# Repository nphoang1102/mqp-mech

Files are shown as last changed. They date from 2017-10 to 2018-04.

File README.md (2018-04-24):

# WPI's MQP Yale's Open Hand Hardware Design
This repository is the hardware design iteration for the Yale's Open Hand MQP at WPI. Please find under the A, B, C term folders the iterations and README.md file that will describe the contain of each folders.

Everything in this repository requires SolidWork 2018 to open and view. The final assembly file can be accessed via C-term/Testing/test_hand_(FINISHED).SLDASM.

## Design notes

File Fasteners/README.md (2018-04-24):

# List of nuts and screws used for WPI MQP Yale's Open Hand

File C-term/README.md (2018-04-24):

# MQP Yale's Open Hand Prototype

### Modified Parts
The files in this folder are modifications to _Iteration 2 model_ to address the problem gear positioning and incorporate PCB board and housing to the current base for a complete hand.
The modifications are:
  - Base: add mounting column onto base for PCB board mount.
  - Gear finger: increase center hole size to fit hollow shaft whichh will fix the position of the gear.
  - Mount motors: change to account for size of the motor.
  - Housing: housing with air ventillation system for cooling motors.
  
### Mounting Parts
The files in this folder are off-shelf parts:
  - DC fan models.
  - Housing for glove electric board.
  - Adapter to Baxter arm model.

### PCB Mount
The files in this folder is the PCB Board model.

### STL toPrint
Dedicated folder for STL files and 3D printing requests.

### Testing
The files in this folder are assemblies for interference check of final prototype.

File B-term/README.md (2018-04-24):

# MQP Yale's Open Hand Iteration 1 & 2

### ReflexOne Finger
The file in this folder is assembly of finger model of Reflex One (source from *_RightHand Robotics_*). 

### Prototype 1
The files in this folder are for iteration 1 model: 
  - Change in close distance between two front fingers.
  - Introduce new gear type - two stage gear, to reduce number of gears thus reduce total base size.

The files are:
  - Motor models: AX12 (with removed back cover) and XL320.
  - Mounting models for motors.
  - Gear models.
  - Base models for hand: top plate and bottom plate.
  - Assembly test models: 
    - Model to verify position of gears and motors.
    - Model of AX12 motor with pulley attached.
    - Model of full assembly to check interference.
  - Excel file of ratio calculations generated from Python script in A-term folder.
    - May use database software to find desired torque reduction ratio with related gear dimensions by importing data from _Ratio Calculation.xlsx_.
  - Archive file of STL files for 3D printing.

The purpose of iteration 1:
  - Test the new design of two front finger gears with controlled glove
  
### Prototype 1 Fixes (Not Prototype 2 Yet)
The files in this folder are fixes for iteration 1 model to make it performs better and smoother.
The files are the same as in _Prototype 1_ folder with adjusted changes in each file.

### Prototype 2
The files in this folder are for iteration 2 model:
  - Change in distance of two front fingers to avoid interference of two finger knuckles.
  - Change in base shape for aesthetic purpose.

The file types are the same as in _Prototype 1_ folder with addition of a separated folder for STL files.
The file types are re-named for searching purpose:
  - *gear_A*: types of gear.
  - *mount_A*: types of mount.
  - *base_A*: types of base.
  - *test_A*: types of testing models.

Everything in this folder requires SolidWork 2018, Microsoft Excel, and Word Editor (or PyCharm for the Python script) to open and view.

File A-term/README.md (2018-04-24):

# MQP Yale's Open Hand Iteration 0

The files under folder _ReflexOne Finger_ is assembly of finger model of Reflex One (source from **_RightHand Robotics_**). This model is also used for subsequent iterations for interference check.

The files in this folder are:
- Motor models: AX12 (with removed back cover) and XL320.
- Mounting models for motors.
- Gear models: to create new gear models with different dimension, make a copy of _Gear.SLDPRT_ and modify to desired dimension.
- Base models for hand: top plate and bottom plate.
- Assembly test models:
  - Model to verify position of gears and motors.
  - Model of AX12 motor with pulley attached.
  - Model of full assembly to check interference.
- Python script:
  - To create list of gear dimensions and related torque reduction ratio then export to _Gear Measurements.xlsx_.
  - May use database software to find desired torque reduction ratio with related gear dimensions by importing data from _Gear Measurements.xlsx_.

The purpose of iteration 0:
- Test the mechanism: gear train.
- Verify how well the 3D printed parts assembled together.
- Verify how well the details of parts were printed.

Everything in this folder requires SolidWork 2018, Microsoft Excel, and Word Editor (or PyCharm for the Python script) to open and view.

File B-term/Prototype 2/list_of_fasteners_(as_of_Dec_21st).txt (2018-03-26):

Screws:
M2 x 35mm
M3 x 6mm
M3 x 22mm
M3 x 35mm
M4 x 18mm
M4 x 20mm
M4 x 25mm
M4 x 40mm
M6 x 20mm

Nuts:
M3
M4
M6

Shaft:
30mm x 2mm round shaft: 20

Nozzle: 0.25/ 0.3/ 0.35/ 0.4/ 0.5/ 0.8

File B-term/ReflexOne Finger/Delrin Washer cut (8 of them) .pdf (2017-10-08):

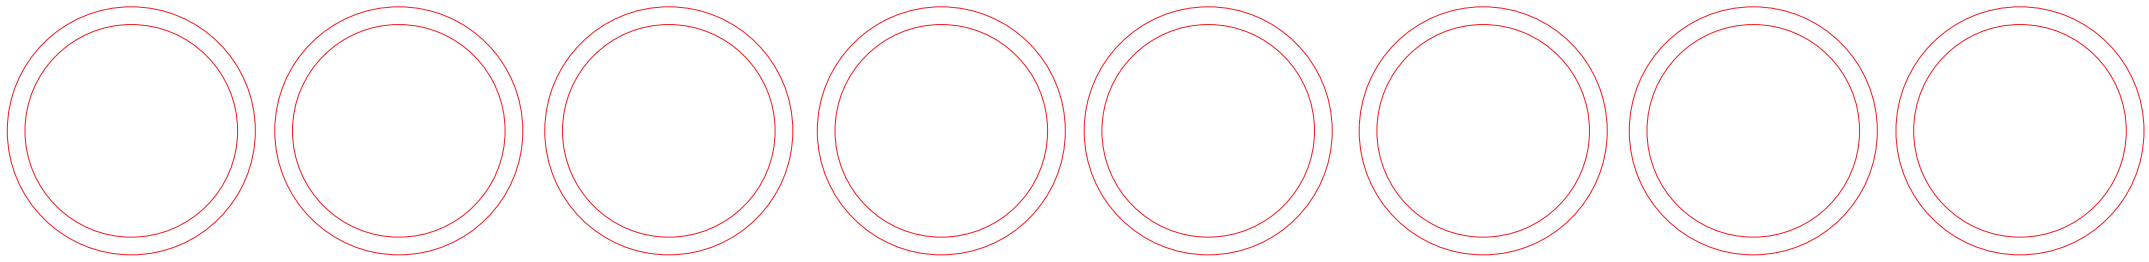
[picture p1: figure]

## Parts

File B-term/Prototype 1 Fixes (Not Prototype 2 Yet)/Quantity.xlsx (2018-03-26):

Parts | Quantity
XL320_thumb_mount | 2
knuckle_mount_test_modified | 1
AX12_thumb_mount | 1
AX12_fingers_mount | 1
two_stage_gear | 1
drive_gear | 1
finger_gear_left | 1
finger_gear_right | 1
base_prototype_test | 1
top_part_base_prototype | 1
TOTAL | 11

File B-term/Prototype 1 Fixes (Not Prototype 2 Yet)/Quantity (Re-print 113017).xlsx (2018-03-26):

Parts | Quantity
AX12_fingers_mount | 1
two_stage_gear | 1
gear_rod | 1
TOTAL | 3

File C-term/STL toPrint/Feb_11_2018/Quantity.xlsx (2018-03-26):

Parts | Quantity
base_prototype_bottom_(Feb_9_2018) | 1
base_prototype_top_(Feb_9_2018) | 1
mount_finger_left | 1
mount_finger_right | 1
mount_thumb | 1
Total | 5

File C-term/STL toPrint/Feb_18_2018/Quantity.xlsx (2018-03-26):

Parts | Quantity
base_prototype_bottom_(Feb_18_2018) | 1
base_prototype_top_(Feb_18_2018) | 1
mount_finger_left | 1
mount_finger_right | 1
glove_housing_top | 1
glove_housing_bottom | 1
Total | 6

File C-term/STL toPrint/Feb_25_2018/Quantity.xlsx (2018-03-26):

Parts | Quantity
housing | 1
mount_finger_left | 1
mount_finger_right | 1
Total | 3

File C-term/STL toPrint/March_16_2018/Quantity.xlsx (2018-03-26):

Parts | Quantity
glove_housing_top | 1
glove_housing_bottom | 1
camera_adapter_base_modified | 1
Total | 3

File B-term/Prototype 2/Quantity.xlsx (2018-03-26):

Parts | Quantity
base_prototype_bottom | 1
base_prototype_top | 1
gear_drive | 1
gear_finger_left | 1
gear_finger_right | 1
gear_intermediate | 1
gear_two_stage | 1
housing | 1
mount_finger_left | 1
mount_finger_right | 1
mount_knuckle_test_modified | 1
mount_thumb | 1
mount_XL320_drive | 1
mount_XL320_thumb | 1
TOTAL | 14

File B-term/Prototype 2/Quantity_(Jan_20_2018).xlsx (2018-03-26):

Parts | Quantity
base_prototype_top_(Jan_20_2018) | 1
shaft_connector | 8
TOTAL | 9

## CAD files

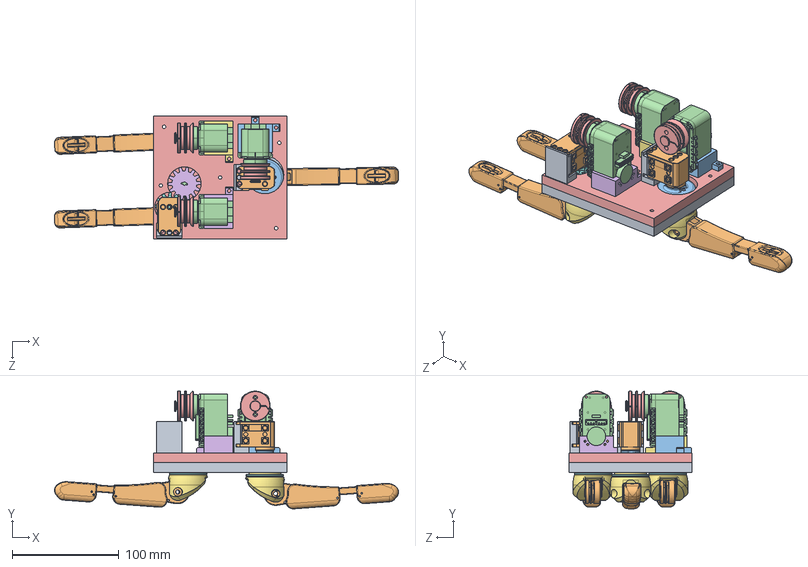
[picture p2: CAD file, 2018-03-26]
A-term/PROTOTYPE_0TH.SLDASM
322.5 x 110.4 x 115.0 mm
base_prototype_test
finger_gear x 2
intermediate_gear
AX-12A (back off) x 3
pulley_spool_test x 3
AX12_front_mount_left
Knuckle mark 3 x 3
Delrin Washer x 3
M3 EZ LOCK (5.1MM HOLE) 6.5mm insert x 6
Finger x 3
knuckle_mount_test_modified
intermediate_gear_bottom_level
top_part_base_prototype
intermediate_gear_top_level
AX12_front_mount_right
drive_gear
XL320_drive_gear_mount x 2
XL320 x 2
AX12_thumb_mount
connect_shaft

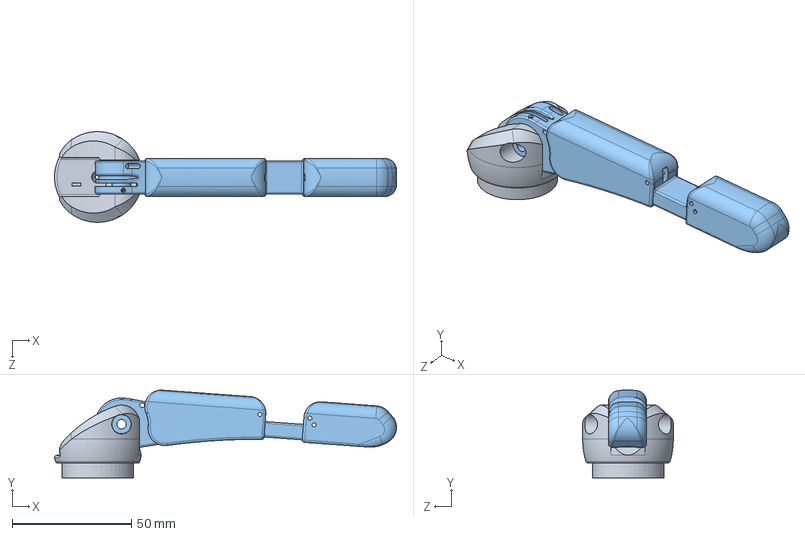
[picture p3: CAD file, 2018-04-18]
A-term/ReflexOne Finger/Concept 2 FINGER.SLDASM
143.3 x 36.8 x 38.0 mm
Knuckle mark 3
M3 EZ LOCK (5.1MM HOLE) 6.5mm insert x 2
Finger

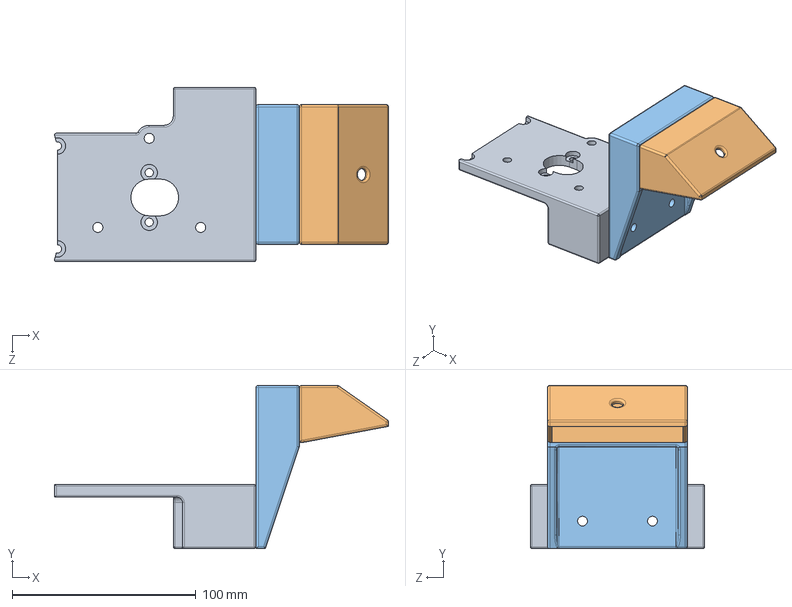
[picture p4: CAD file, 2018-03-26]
C-term/Mounting Parts/mounting_house/Camera Mount/WristCameraMount.SLDASM
181.9 x 88.9 x 95.0 mm
ReflexHand_Camera_Adaptor_v2
Wedge
WristCameraMount_Spacer

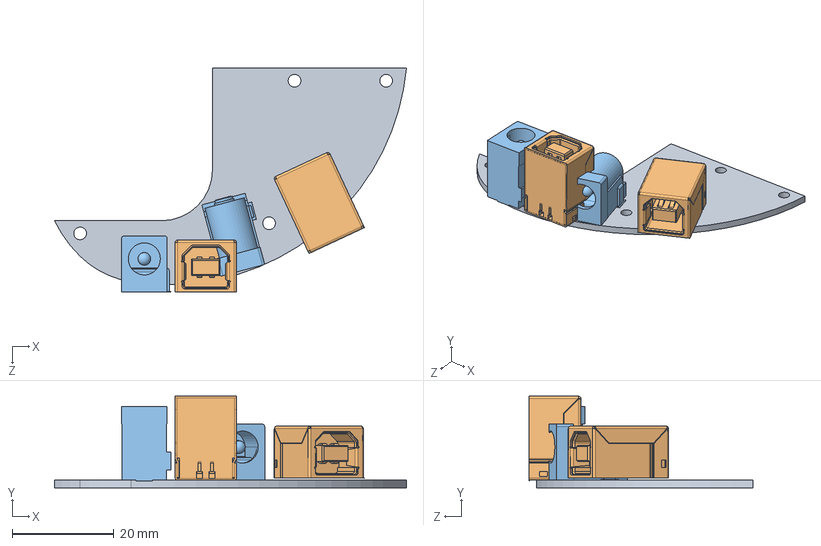
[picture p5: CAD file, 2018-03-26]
C-term/PCB Mount/PCB board Assembly.SLDASM
69.2 x 18.0 x 44.0 mm
Pcb board base
USB type b
power jack

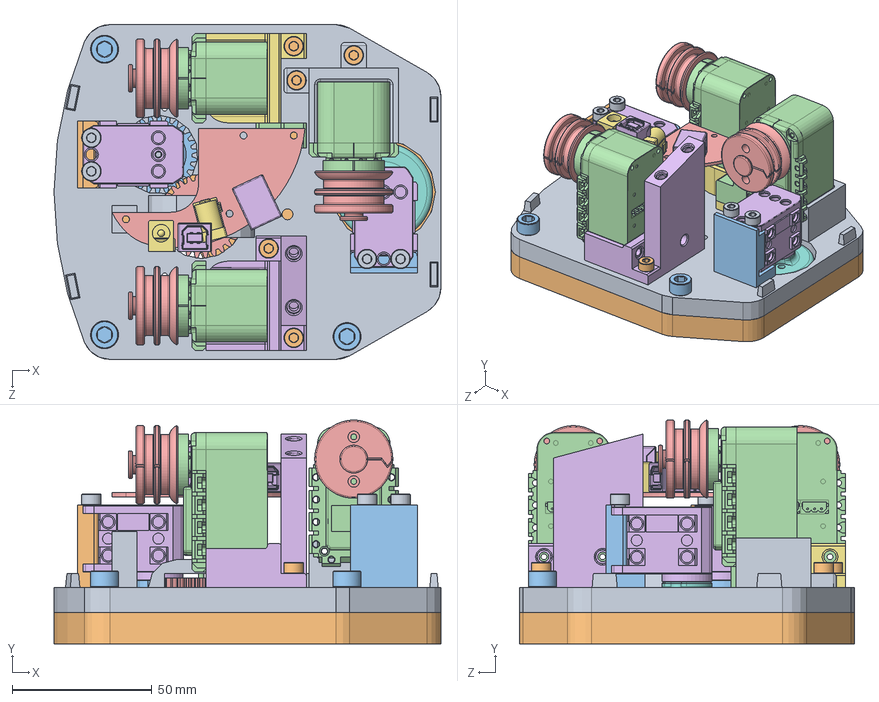
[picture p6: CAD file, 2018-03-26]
C-term/Testing/test_top_part_Jan_30_2018_(FINISHED).SLDASM
138.7 x 80.2 x 120.0 mm
base_prototype_top_(Jan_30_2018)
base_prototype_bottom
gear_drive
gear_rod_(NOT_PRINT)
gear_two_stage
mount_finger_left
mount_finger_right
mount_knuckle_test_modified
mount_thumb
mount_XL320_drive
mount_XL320_thumb
AX-12A (back off) x 3
pulley_spool_test x 3
XL320 x 2
Hex_Nut_M4 x 10
Hex_Nut_M6 x 3
M4_x_40mm x 4
M4_x_25mm x 6
M6_x_20mm x 3
PCB_board_mount_standing
Pcb board base
USB type b
power jack

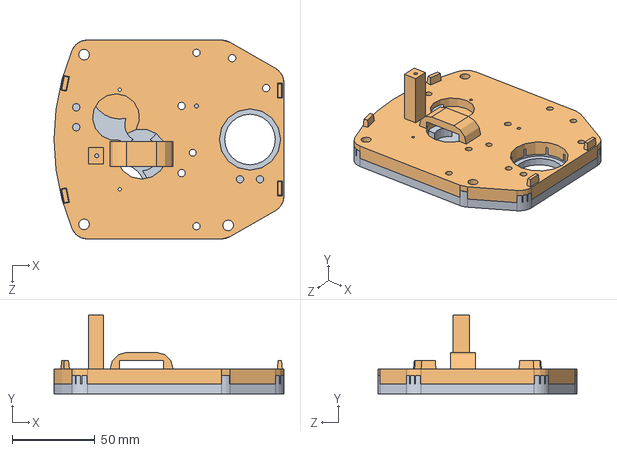
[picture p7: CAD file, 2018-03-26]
C-term/Testing/test_position_Feb_11_2018.SLDASM
138.7 x 47.5 x 120.0 mm
base_prototype_bottom_(Feb_9_2018)
base_prototype_top_(Feb_9_2018)

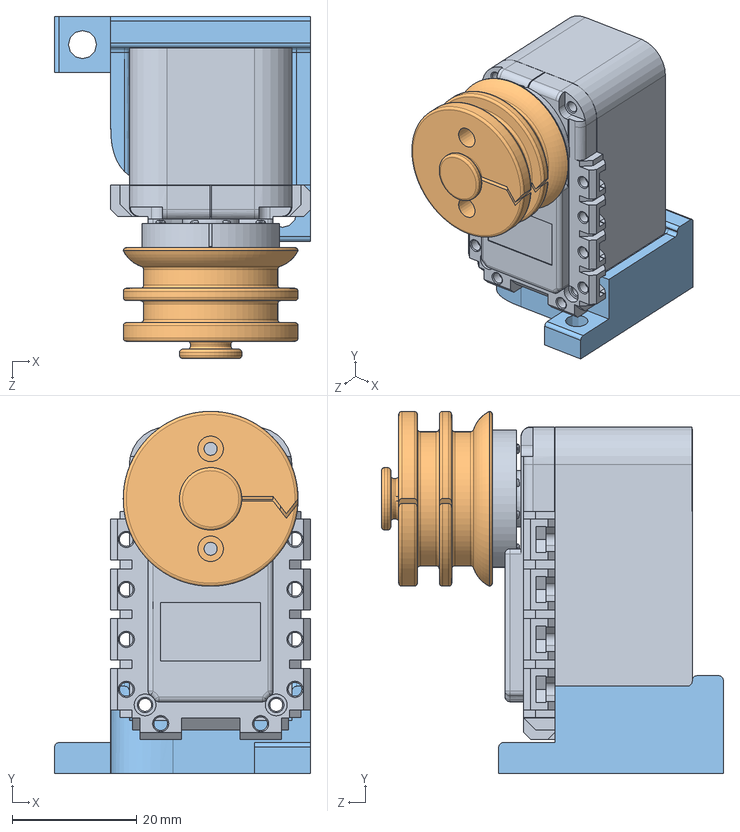
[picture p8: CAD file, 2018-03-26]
B-term/Prototype 2/test_motor_pulley_thumb.SLDASM
41.0 x 58.0 x 54.8 mm
AX-12A (back off)
pulley_spool_test
mount_finger_left

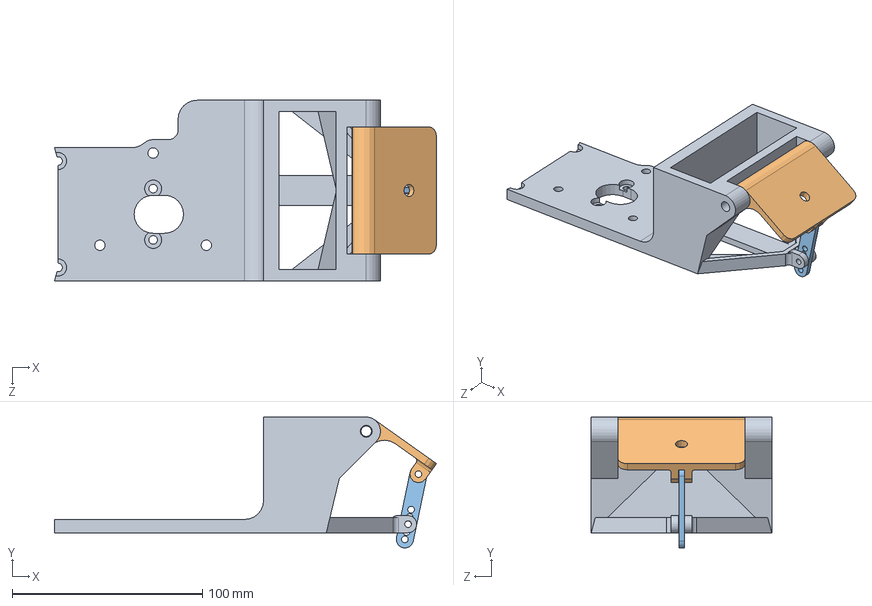
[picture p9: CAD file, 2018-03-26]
C-term/Mounting Parts/mounting_house/Camera Mount/WristCameraMountAdjustable.SLDASM
201.0 x 68.9 x 95.0 mm
Camera Adapter Base
Rotate Joint
Adjustment plate

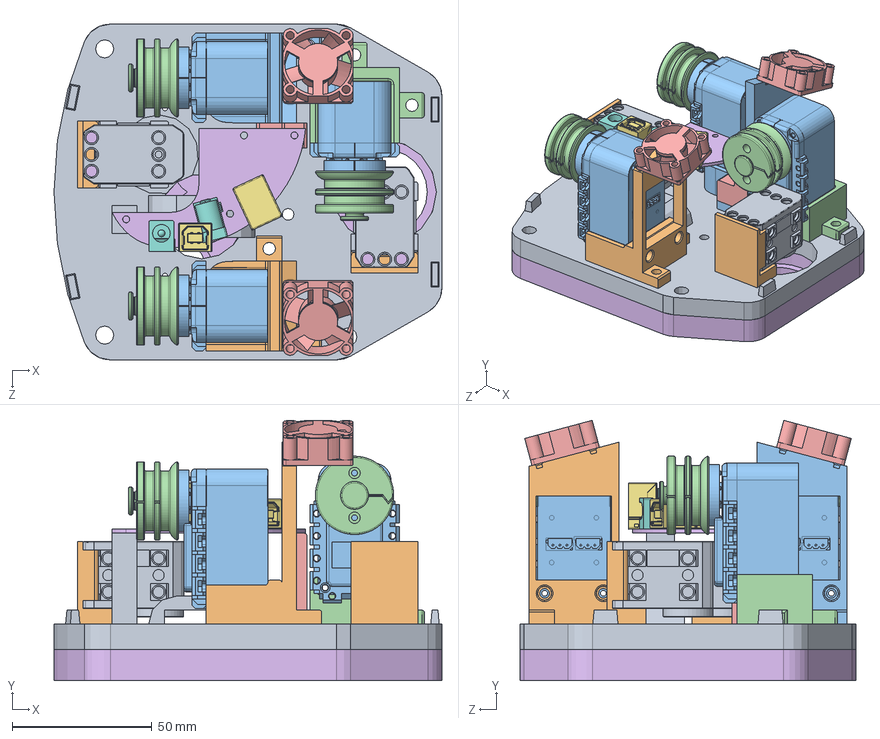
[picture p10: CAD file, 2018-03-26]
C-term/Testing/test_top_part_Feb_9_2018_(FINISHED).SLDASM
138.7 x 93.0 x 120.0 mm
base_prototype_top_(Feb_9_2018)
mount_finger_left
mount_finger_right
mount_thumb
PCB_board_mount_standing
Pcb board base
USB type b
power jack
XL320 x 2
XL320_thumb_mount x 2
AX-12A (back off) x 3
pulley_spool_test x 3
DC Fan - 25X25X10 x 2
base_prototype_bottom_(Feb_9_2018)

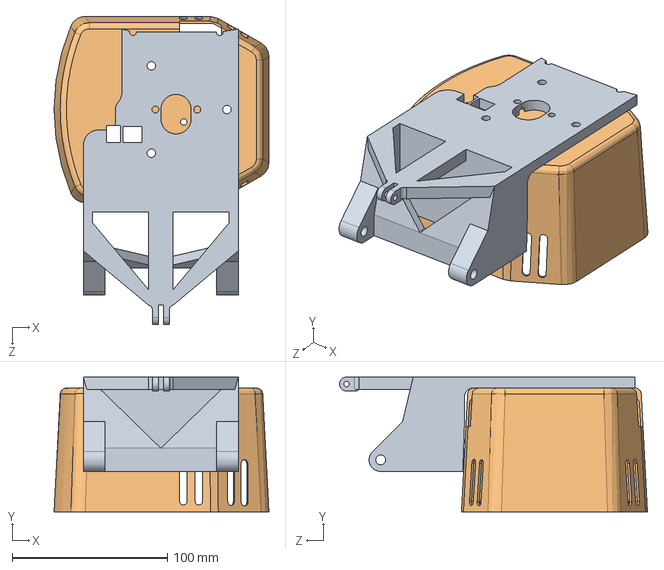
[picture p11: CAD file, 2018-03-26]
C-term/Testing/test_adapter_housing.SLDASM
138.7 x 87.0 x 198.6 mm
camera_adapter_base_modified
housing_(FINISHED)

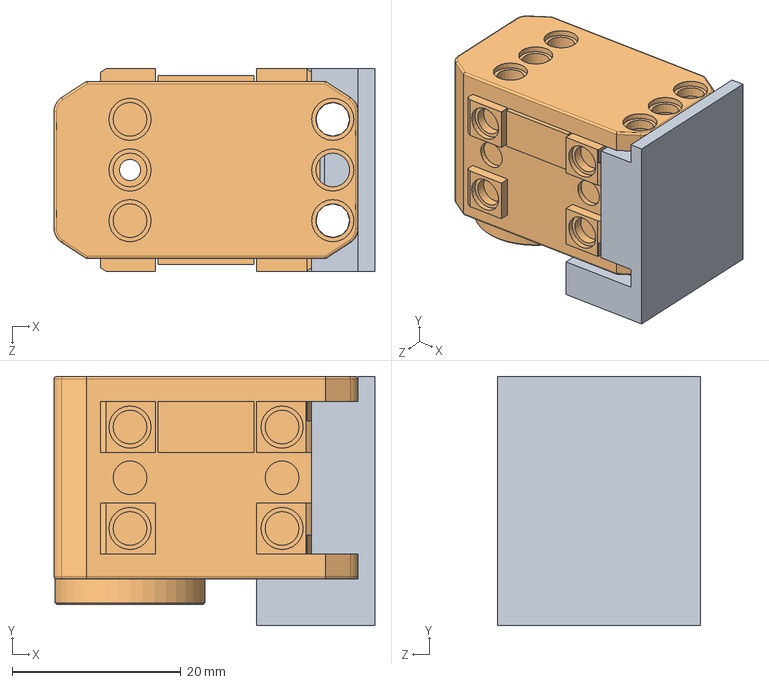
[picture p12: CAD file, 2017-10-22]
A-term/drive_gear_mount_assembly.SLDASM
38.0 x 29.5 x 24.0 mm
XL320_drive_gear_mount
XL320

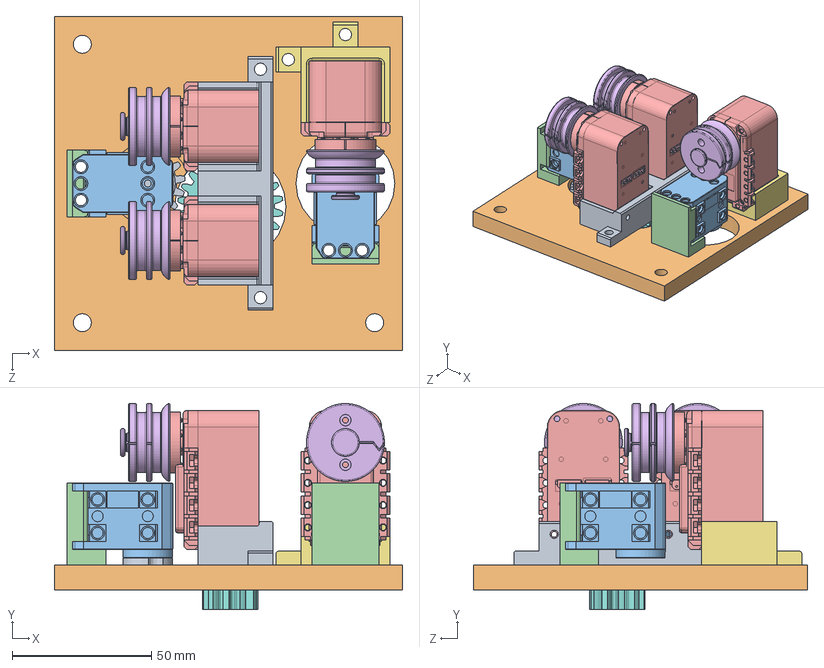
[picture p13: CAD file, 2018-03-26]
B-term/Prototype 1 Fixes (Not Prototype 2 Yet)/test_top_part.SLDASM
125.0 x 74.0 x 120.0 mm
AX12_fingers_mount
top_part_base_prototype
XL320 x 2
XL320_thumb_mount x 2
AX-12A (back off) x 3
pulley_spool_test x 3
AX12_thumb_mount
two_stage_gear
drive_gear

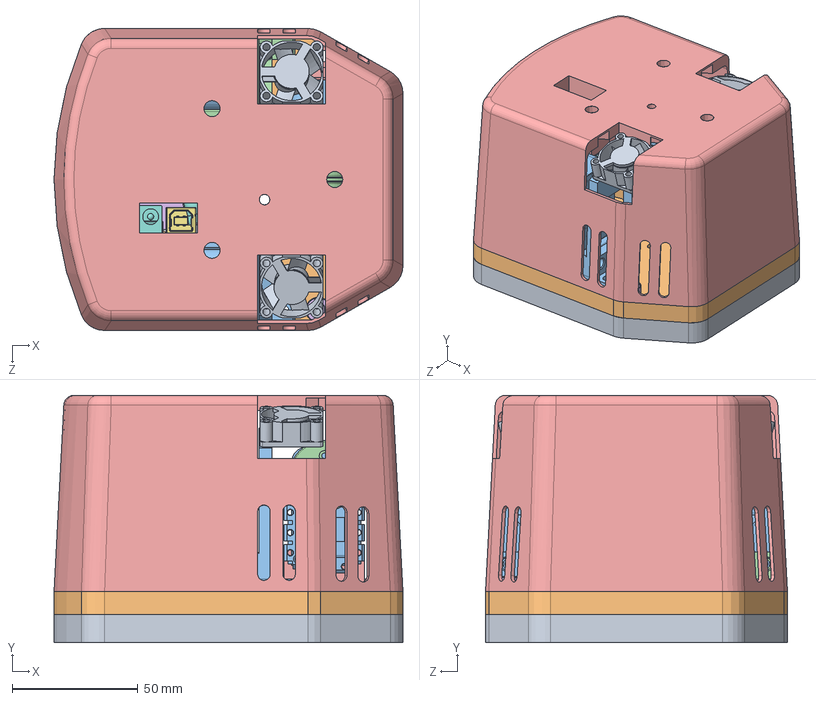
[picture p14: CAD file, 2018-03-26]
C-term/Testing/test_top_part_with_housing_Feb_25_2018_(NOT_FINISHED).SLDASM
138.7 x 98.2 x 120.0 mm
base_prototype_bottom_(Feb_18_2018)
base_prototype_top_(Feb_18_2018)
mount_finger_left
mount_finger_right
mount_thumb
Pcb board base
USB type b
power jack
DC Fan - 25X25X10 x 2
PCB_board_mount_standing
AX-12A (back off) x 3
pulley_spool_test x 3
housing_(FINISHED)
M6_x_20mm x 3

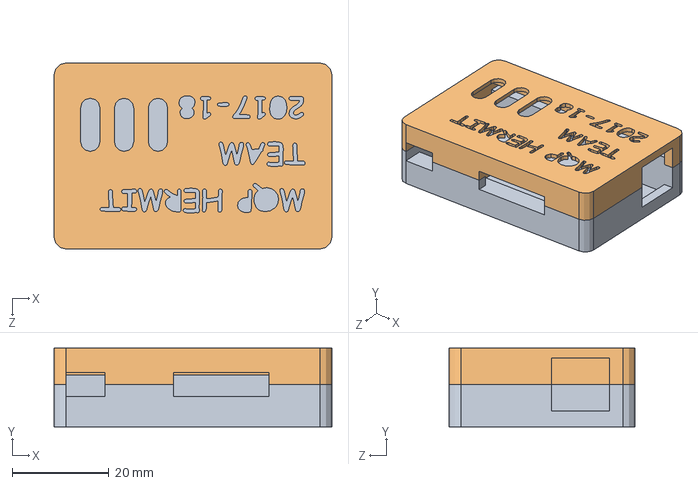
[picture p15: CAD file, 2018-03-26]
C-term/Testing/test_glove_housing.SLDASM
57.5 x 16.2 x 38.5 mm
glove_housing_bottom
glove_housing_top

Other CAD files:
B-term/ReflexOne Finger/Concept 2 FINGER.SLDASM
C-term/Testing/test_top_part_Feb_18_2018_(FINISHED).SLDASM
B-term/Prototype 1 Fixes (Not Prototype 2 Yet)/XL320_and_mount.SLDASM
B-term/Prototype 1 Fixes (Not Prototype 2 Yet)/motor_pulley_thumb.SLDASM
A-term/(NO_MODIFY)_base_prototype_test.SLDPRT
A-term/AX-12A (back off).SLDPRT
A-term/AX12_front_mount_left.SLDPRT
A-term/AX12_front_mount_right.SLDPRT
A-term/AX12_thumb_mount.SLDPRT
A-term/XL320.SLDPRT
A-term/XL320_drive_gear_mount.SLDPRT
A-term/base_prototype_test.SLDPRT
A-term/body_test.SLDPRT
A-term/connect_shaft.SLDPRT
A-term/drive_gear.SLDPRT
A-term/finger_gear.SLDPRT
A-term/gear.SLDPRT
A-term/gears_train.SLDASM
A-term/intermediate_gear.SLDPRT
A-term/intermediate_gear_bottom_level.SLDPRT
A-term/intermediate_gear_top_level.SLDPRT
A-term/knuckle_mount_test_modified.SLDPRT
A-term/motor_pulley_left.SLDASM
A-term/motor_pulley_right.SLDASM
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

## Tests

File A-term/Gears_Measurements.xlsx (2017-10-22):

Gear 1 (Intermediate Gear, Intermediate Gear Bottom Level) |  |  |  |  |  |  |  | Gear 2 (Finger Gear)
Number of Teeth | Outside Diameter | Module | Diametral Pitch | Pitch Diameter | Pitch | Primitive Diameter/ Base Circle | Foot Diameter | Number of Teeth | Outside Diameter | Module | Diametral Pitch | Pitch Diameter | Pitch | Primitive Diameter/ Base Circle | Foot Diameter
15 | 27 | 1.588235294 | 0.6296296296 | 23.82352941 | 4.989588332 | 23.82352941 | 20.64705882 | 20 | 35 | 1.590909091 | 0.6285714286 | 31.81818182 | 4.997988313 | 31.81818182 | 28.63636364
16 | 27 | 1.5 | 0.6666666667 | 24 | 4.71238898 | 24 | 21 | 21 | 35 | 1.52173913 | 0.6571428571 | 31.95652174 | 4.780684473 | 31.95652174 | 28.91304348
17 | 27 | 1.421052632 | 0.7037037037 | 24.15789474 | 4.464368508 | 24.15789474 | 21.31578947 | 22 | 35 | 1.458333333 | 0.6857142857 | 32.08333333 | 4.581489286 | 32.08333333 | 29.16666667
18 | 27 | 1.35 | 0.7407407407 | 24.3 | 4.241150082 | 24.3 | 21.6 | 23 | 35 | 1.4 | 0.7142857143 | 32.2 | 4.398229715 | 32.2 | 29.4
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

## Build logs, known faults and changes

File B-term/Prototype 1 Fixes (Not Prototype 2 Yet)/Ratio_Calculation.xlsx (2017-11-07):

OD_INTER | OD_FINGER | OD_TOP | OD_DRIVE | NO_TEETH_DRIVE_GEAR | NO_TEETH_TOP_GEAR | NO_TEETH_FINGER_GEAR | NO_TEETH_INTERMEDIATE_GEAR | RATIO
15 | 35 | 33 | 27 | 16 | 20 | 26 | 10 | 0.3077
15 | 35 | 33 | 27 | 20 | 25 | 26 | 10 | 0.3077
15 | 35 | 34 | 27 | 17 | 22 | 26 | 10 | 0.2972
15 | 35 | 34 | 27 | 21 | 27 | 26 | 10 | 0.2991
15 | 35 | 34 | 28 | 12 | 15 | 26 | 10 | 0.3077
15 | 35 | 35 | 27 | 15 | 20 | 26 | 10 | 0.2885
15 | 35 | 35 | 27 | 18 | 24 | 26 | 10 | 0.2885
15 | 35 | 35 | 27 | 22 | 29 | 26 | 10 | 0.2918
15 | 35 | 35 | 28 | 10 | 13 | 26 | 10 | 0.2959
15 | 35 | 35 | 28 | 14 | 18 | 26 | 10 | 0.2991
15 | 35 | 35 | 28 | 18 | 23 | 26 | 10 | 0.301
15 | 35 | 35 | 28 | 22 | 28 | 26 | 10 | 0.3022
15 | 35 | 36 | 27 | 10 | 14 | 26 | 10 | 0.2747
15 | 35 | 36 | 27 | 13 | 18 | 26 | 10 | 0.2778
15 | 35 | 36 | 27 | 16 | 22 | 26 | 10 | 0.2797
15 | 35 | 36 | 27 | 19 | 26 | 26 | 10 | 0.2811
15 | 35 | 36 | 28 | 12 | 16 | 26 | 10 | 0.2885
15 | 35 | 36 | 28 | 19 | 25 | 26 | 10 | 0.2923
15 | 35 | 36 | 28 | 22 | 29 | 26 | 10 | 0.2918
15 | 35 | 36 | 29 | 15 | 19 | 26 | 10 | 0.3036
15 | 35 | 36 | 29 | 19 | 24 | 26 | 10 | 0.3045
15 | 35 | 36 | 29 | 23 | 29 | 26 | 10 | 0.305
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

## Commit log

2017-10-04 setup our repo for mechanical files
    [Gears_Measurements.xlsx, Palm_Mark3 - Copy.SLDPRT, base_prototype_test.SLDPRT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]
2017-10-07 Add unfinished CAD model
    [(NO_MODIFY)_base_prototype_test.SLDPRT, Gears_Measurements.xlsx, PROTOTYPE_0TH.SLDASM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]
2017-10-08 Updated 08_Oct_2017
    [Gears_Measurements.xlsx, PROTOTYPE_0TH.SLDASM, drive_gear.SLDPRT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]
2017-10-26 Delete Gears_Measurements.xlsx
    Deleted to use new Ratio_Calculation.xlsx file
    [Gears_Measurements.xlsx]
2017-10-26 Change in ratio_calculation.py for data output to Ratio.Calculation.xlsx
    [Gears_Measurements.xlsx, PROTOTYPE_0TH.SLDASM, Ratio_Calculation.xlsx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]
2017-11-07 rolled back to the end of A-term, this model was sent to Danny for print, put everything under A-term folder now.
    [(NO_MODIFY)_base_prototype_test.SLDPRT, AX-12A (back off).SLDPRT, AX12_front_mount_left.SLDPRT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]
2017-11-07 remove circular feature and lower holes in AX-12 mount, remove thread in top and base parts, change mount model to fit two motors, adjust positions for front motors
    [AX-12A (back off).SLDPRT, AX12_fingers_mount.SLDPRT, AX12_front_mount_left.SLDPRT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]
2017-11-07 moved changes (circular feature + lower holes + thread removal, mount model fit two motors, adjust positions) into B-term folder
    [AX-12A (back off).SLDPRT, AX12_fingers_mount.SLDPRT, AX12_thumb_mount.SLDPRT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]
2017-11-07 somehow the previous merge does not update to the working version of A term
    [(NO_MODIFY)_base_prototype_test.SLDPRT, AX-12A (back off).SLDPRT, AX12_front_mount_left.SLDPRT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]
2017-11-07 rebuilt the assembly models without error
    [PROTOTYPE_0TH.SLDASM, TEST_POSITION_PROTOTYPE_1.SLDASM]
2018-03-26 updated mechanical design for robotics hand up to C-term of 2018, with the housing for the data glove
    [AX-12A (back off).SLDPRT, AX-12A connector.SLDPRT, AX12_fingers_mount (before modified to fit two-stage gear).SLDPRT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]
2018-04-18 found the finger for reflex... no need to find that part now
    [Concept 2 FINGER.SLDASM]
2018-04-18 re-aligned the fingers in the final assembly now, looks somewhat better now. Gonna need to structure the CAD design in the future for documentation
2018-04-24 add Readme.md for highlevel repo view about prototype
